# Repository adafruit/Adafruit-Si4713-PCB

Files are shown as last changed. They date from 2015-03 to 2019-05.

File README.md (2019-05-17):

# Adafruit Si4713 FM Transmitter Breakout PCB
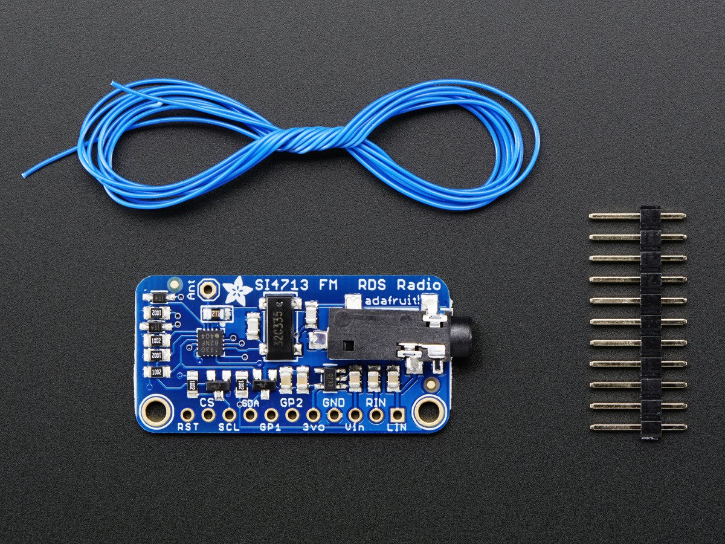
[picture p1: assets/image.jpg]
<a href="http://www.adafruit.com/products/1958"><br/>
Click here to purchase one from the Adafruit shop</a>

Become your very own pirate radio station with this FM radio transmitter. This breakout board, based on the best-of-class Si4713, is an all-in-one stereo audio FM transmitter that can also transmit RDS/RBDS data!

Wire up to your favorite microcontroller (we suggest an Arduino) to the I2C data lines to set the transmit frequency and play line-level audio into the stereo headphone jack. Boom! Now you are the media. Listen using any FM receiver such as your car or pocket radio receiver - this is an easy way to transmit audio up to about 10 meters / 30 feet away.

PCB files for Adafruit Si4713 FM Transmitter Breakout. The format is EagleCAD schematic and board layout
- https://www.adafruit.com/product/1958

### License

Adafruit invests time and resources providing this open source design, please support Adafruit and open-source hardware by purchasing products from [Adafruit](https://www.adafruit.com)!

All text above must be included in any redistribution

Designed by Limor Fried/Ladyada for Adafruit Industries.
Creative Commons Attribution/Share-Alike, all text above must be included in any redistribution. 
See license.txt for additional information.

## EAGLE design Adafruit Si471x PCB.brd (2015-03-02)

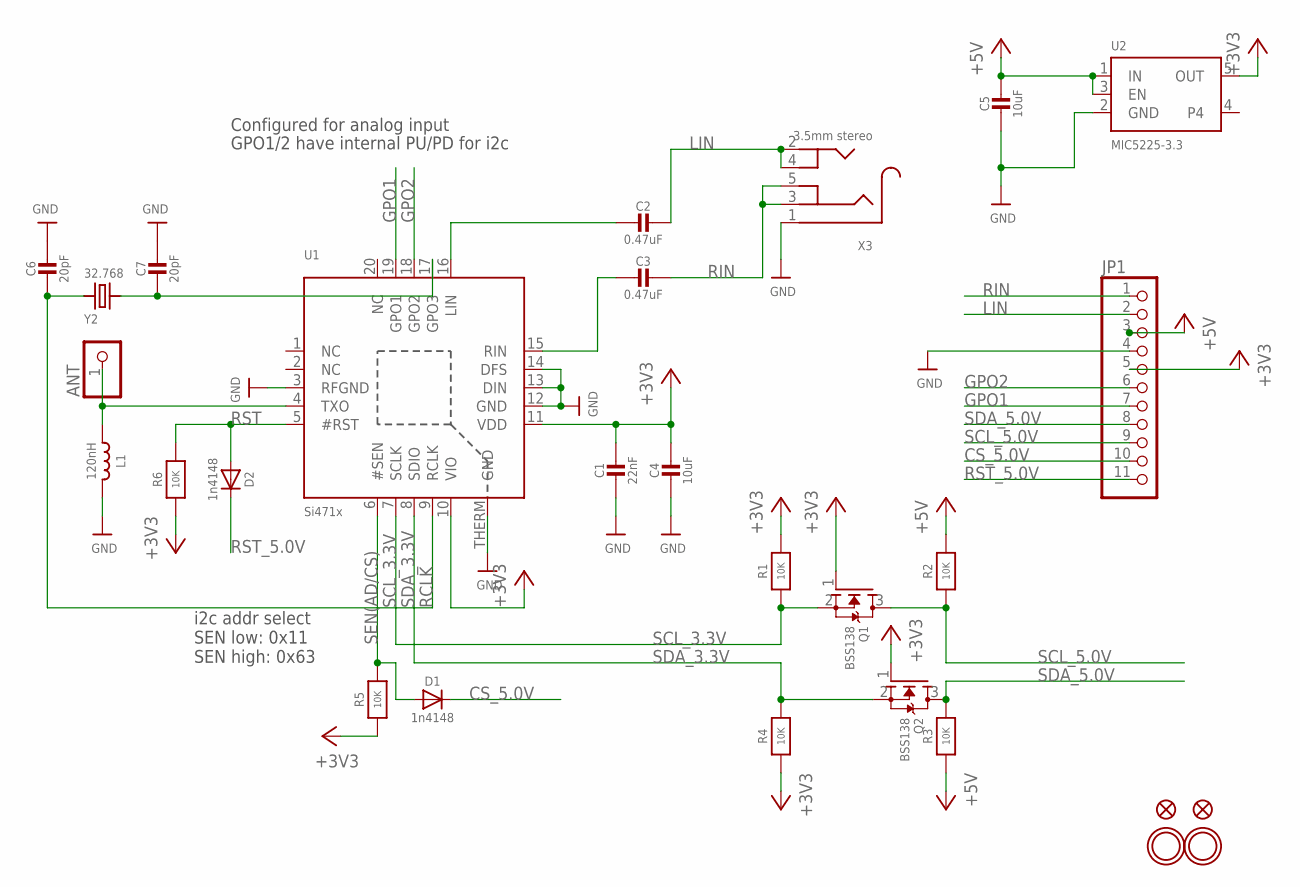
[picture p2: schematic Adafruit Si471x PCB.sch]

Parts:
ANT: PINHD-1X1; 1X01
C1: 22nF; 0805-NO
C2, C3: 0.47uF; 0805-NO
C4, C5: 10uF; 0805-NO
C6, C7: 20pF; 0805-NO
D1, D2: 1n4148; SOD-323
FID1, FID2: FIDUCIAL""; FIDUCIAL_1MM
JP1: HEADER-1X11; 1X11_ROUND
L1: 120nH; _0805
Q1, Q2: BSS138; SOT23
R1, R3, R5, R6: 10K; 0805-NO
R2, R4: 10K; _0805MP
U1: Si471x; SI471X
U2: MIC5225-3.3; SOT23-5
U$15, U$17: MOUNTINGHOLE2.5; MOUNTINGHOLE_2.5_PLATED
X3: 3.5mm stereo; 4UCONN_19269
Y2: 32.768; CRYSTAL_8X3.8

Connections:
+3V3: C1.1, C4.1, JP1.5, Q1.1 (G), Q2.1 (G), R1.2, R4.1, R5.1, R6.1, U1.10 (VIO), U1.11 (VDD), U2.5 (OUT)
+5V: C5.1, JP1.3, R2.2, R3.1, U2.1 (IN), U2.3 (EN)
CS_5.0V: D1.C, JP1.10
GND: C1.2, C4.2, C5.2, C6.1, C7.1, JP1.4, L1.2, U1.3 (RFGND), U1.12 (GND), U1.13 (DIN), U1.14 (DFS), U1.THERM (GND), U2.2 (GND), X3.1
GPO1: JP1.7, U1.19 (GPO1)
GPO2: JP1.6, U1.18 (GPO2)
LIN: C2.1, JP1.2, X3.2, X3.4
unnamed: ANT.1, L1.1, U1.4 (TXO)
unnamed: C2.2, U1.16 (LIN)
unnamed: C3.2, U1.15 (RIN)
unnamed: C7.2, U1.17 (GPO3), Y2.P$4 (2)
RCLK: C6.2, U1.9 (RCLK), Y2.P$1 (1)
RIN: C3.1, JP1.1, X3.3, X3.5
RST: D2.A, R6.2, U1.5 (#RST)
RST_5.0V: D2.C, JP1.11
SCL_3.3V: Q1.2 (S), R1.1, U1.7 (SCLK)
SCL_5.0V: JP1.9, Q1.3 (D), R2.1
SDA_3.3V: Q2.2 (S), R4.2, U1.8 (SDIO)
SDA_5.0V: JP1.8, Q2.3 (D), R3.2
SEN(AD/CS): D1.A, R5.2, U1.6 (#SEN)

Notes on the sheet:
Configured for analog input
GPO1/2 have internal PU/PD for i2c
i2c addr select SEN low: 0x11 SEN high: 0x63

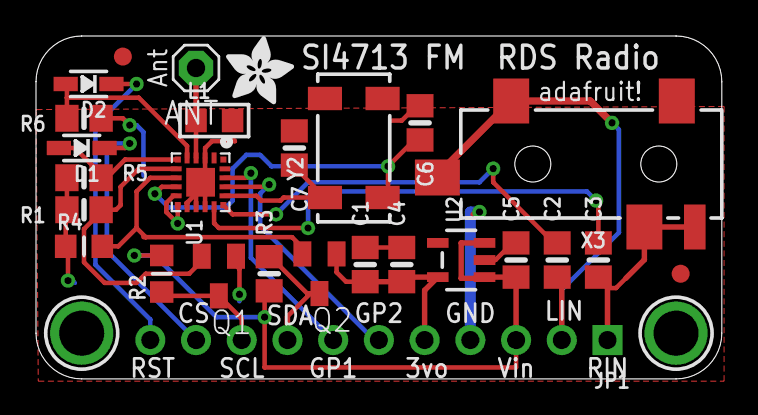
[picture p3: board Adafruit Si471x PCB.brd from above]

Board: 2 copper layers, 38.1 x 19.1 mm, 30 parts (1 on the bottom side), 20 nets.

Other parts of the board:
U$7: ADAFRUIT_3.5MM
U$9: ADAFRUIT_TEXT_20MM

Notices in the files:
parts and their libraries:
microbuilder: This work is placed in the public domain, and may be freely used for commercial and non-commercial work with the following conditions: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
